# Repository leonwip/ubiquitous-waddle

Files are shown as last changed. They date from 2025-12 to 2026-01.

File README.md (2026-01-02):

# ubiquitous-waddle

This is an open-source dual channel CAN FD to USB-C adapter. It is meant to be
used with the Zephyr-based [CANnectivity][1] firmware.

## Firmware

### Building

Assuming you already have a working Zephyr development environment (see
[Getting Started Guide][2]), the firmware workspace can be initialized using:
```sh
west init -m "https://github.com/leonwip/ubiquitous-waddle" --mr main my-workspace
cd my-workspace
west update
```

Then to build the release variant (with reduced logging):
```sh
west build -b ubiquitous_waddle --sysbuild cannectivity/app -- -DSB_CONF_FILE=sysbuild-dfu.conf -DFILE_SUFFIX=usbd_next_release
```

### Flashing

To flash via JLink (SWD):
```sh
west flash --runner jlink
```

To flash via USB DFU:
```
dfu-util -a 0 -D build/app/zephyr/zephyr.signed.bin.dfu
```

## Example Usage

Verify successful connection:
```sh
$ lsusb | grep CANnectivity
Bus 005 Device 014: ID 1209:ca01 Generic CANnectivity USB to CAN adapter
```

Determine interface names:
```sh
$ ip link show type can
16: can0: <NOARP,ECHO> mtu 16 qdisc noop state DOWN mode DEFAULT group default qlen 10
    link/can
17: can1: <NOARP,ECHO> mtu 16 qdisc noop state DOWN mode DEFAULT group default qlen 10
    link/can
```

Bring up the interface (with FD on):
```sh
sudo ip link set can0 up type can bitrate 250000 dbitrate 1000000 fd on
```

Send some frames (`##1` opposed to just `#` turns on BRS):
```sh
cansend can0 123#11.22.33
cansend can0 123##111.22.33
```

## License

CANnectivity is licensed under the [Apache-2.0][3] license. This board is
licensed under the [CERN-OHL-P-2.0](./LICENSE) license.

[1]: https://github.com/CANnectivity/cannectivity
[2]: https://docs.zephyrproject.org/latest/develop/getting_started/index.html
[3]: https://github.com/CANnectivity/cannectivity/blob/main/LICENSE

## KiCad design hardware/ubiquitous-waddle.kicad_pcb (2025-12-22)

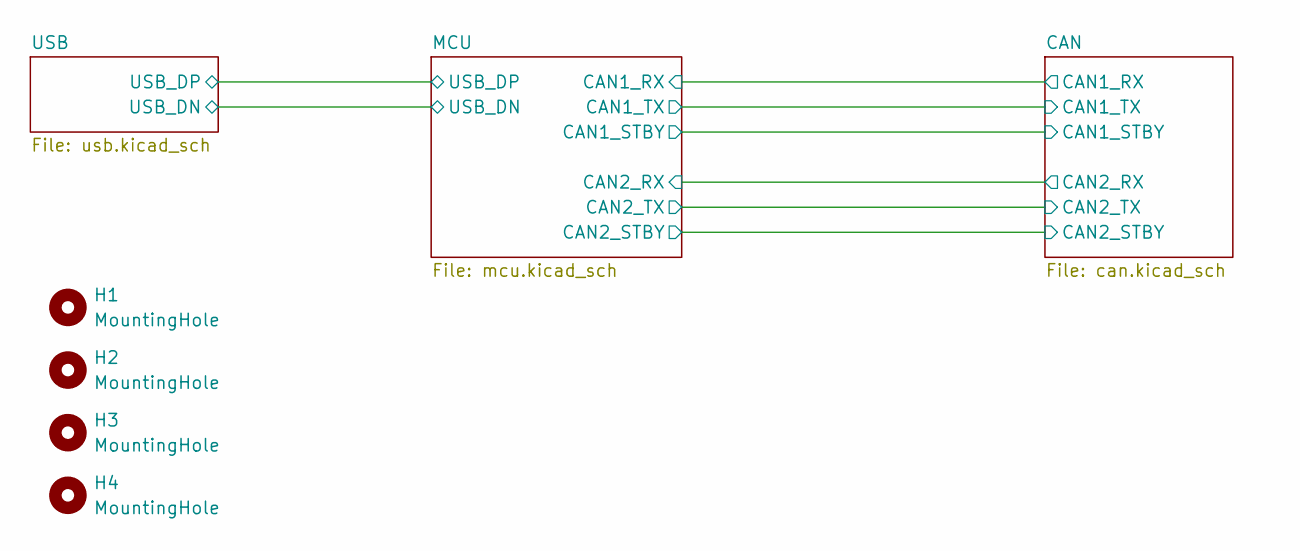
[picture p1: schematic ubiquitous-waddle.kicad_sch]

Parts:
H1, H2, H3, H4: MountingHole; MountingHole_2.7mm_M2.5

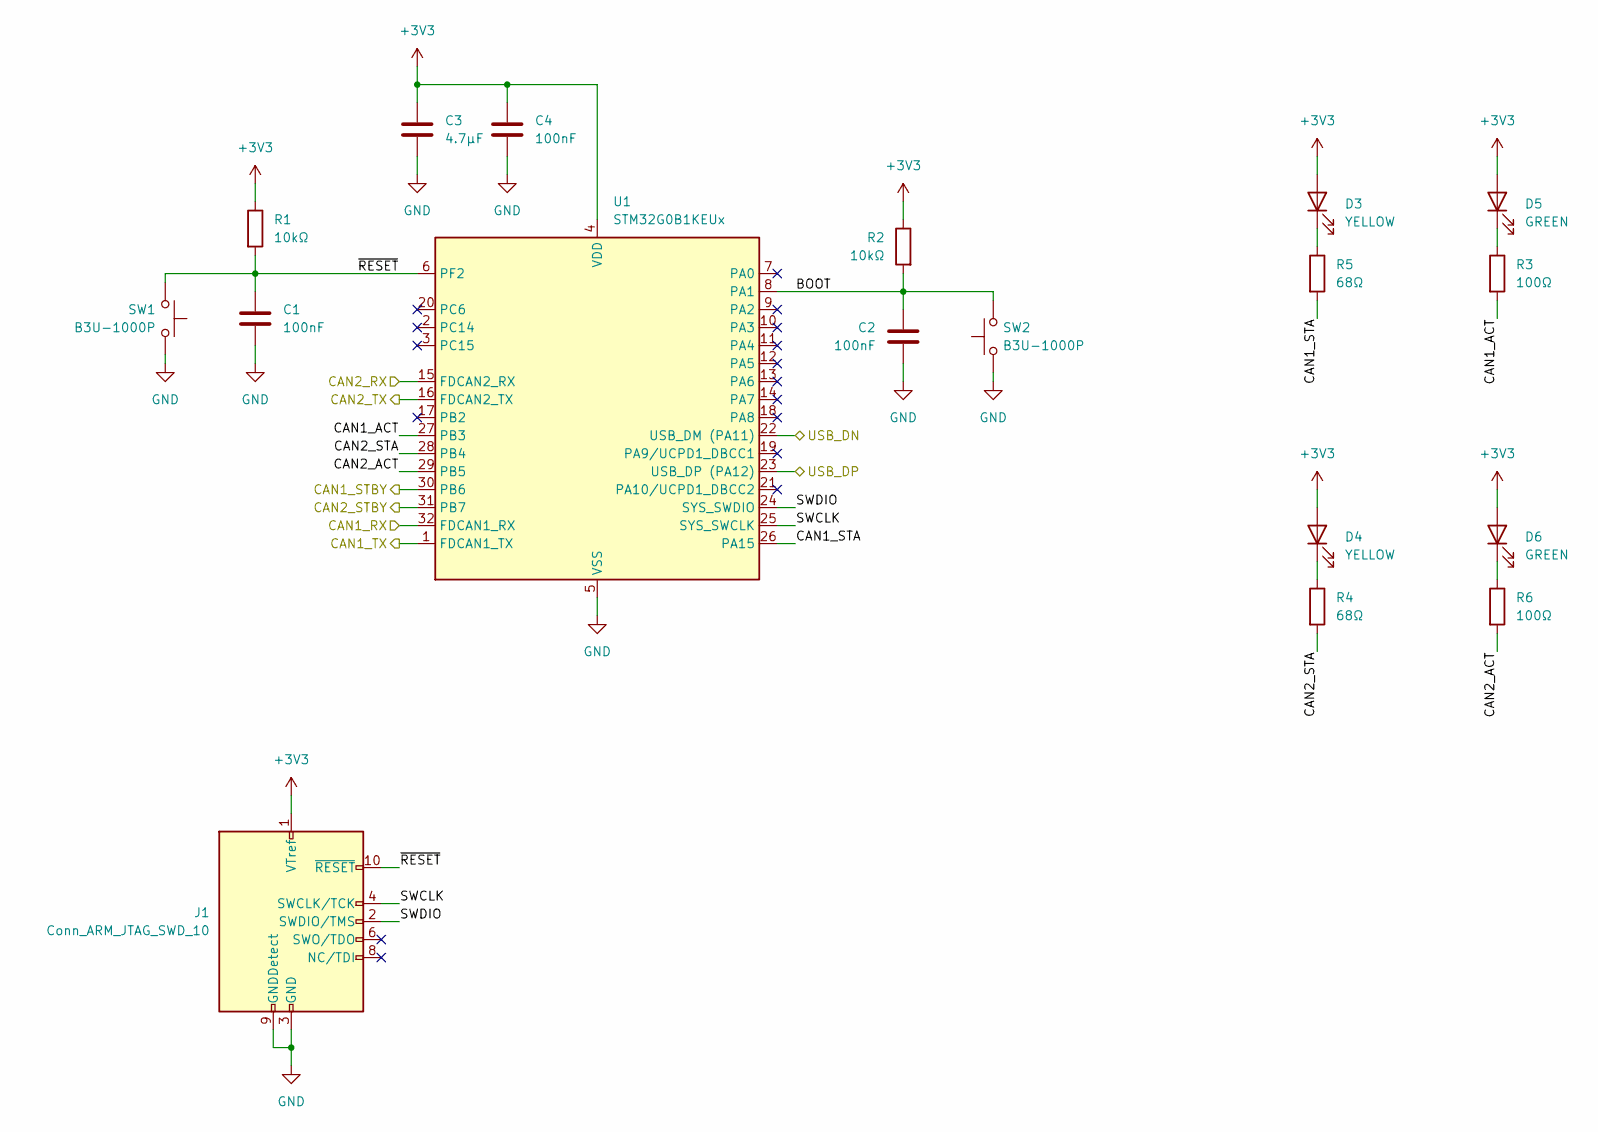
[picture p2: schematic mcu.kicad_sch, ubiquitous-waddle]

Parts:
C1, C2, C4: 100nF; C_0402_1005Metric; Mouser No 81-GRM155R71A104KA1D
C3: 4.7µF; C_0402_1005Metric; Mouser No 81-GRM155R61A475MEAD
D3, D4: YELLOW; LED_0603_1608Metric; Mouser No 710-150060YS55040
D5, D6: GREEN; LED_0603_1608Metric; Mouser No 710-150060GS55040
J1: Conn_ARM_JTAG_SWD_10; PinHeader_2x05_P1.27mm_Vertical_SMD; Mouser No 200-FTSH10501FDVK
R1, R2: 10kΩ; R_0402_1005Metric; Mouser No 603-RC0402FR-0710KL
R3, R6: 100Ω; R_0402_1005Metric; Mouser No 603-RC0402FR-07100RL
R4, R5: 68Ω; R_0402_1005Metric; Mouser No 603-RC0402FR-0768RL
SW1, SW2: B3U-1000P; SW_SPST_B3U-1000P; Mouser No 653-B3U-1000P
U1: STM32G0B1KEUx; QFN-32-1EP_5x5mm_P0.5mm_EP3.45x3.45mm_ThermalVias; Mouser No 511-STM32G0B1KEU6

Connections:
+3V3: C3.1, C4.1, D3.2 (A), D4.2 (A), D5.2 (A), D6.2 (A), J1.1 (VTref), R1.1, R2.1, U1.4 (VDD); also elsewhere on the board
/CAN/CAN1_RX: U1.32 (FDCAN1_RX); also elsewhere on the board
/CAN/CAN1_STBY: U1.30 (PB6); also elsewhere on the board
/CAN/CAN1_TX: U1.1 (FDCAN1_TX); also elsewhere on the board
/CAN/CAN2_RX: U1.15 (FDCAN2_RX); also elsewhere on the board
/CAN/CAN2_STBY: U1.31 (PB7); also elsewhere on the board
/CAN/CAN2_TX: U1.16 (FDCAN2_TX); also elsewhere on the board
/MCU/BOOT: C2.1, R2.2, SW2.2, U1.8 (PA1)
/MCU/CAN1_ACT: R3.2, U1.27 (PB3)
/MCU/CAN1_STA: R5.2, U1.26 (PA15)
/MCU/CAN2_ACT: R6.2, U1.29 (PB5)
/MCU/CAN2_STA: R4.2, U1.28 (PB4)
/MCU/SWCLK: J1.4 (SWCLK/TCK), U1.25 (SYS_SWCLK)
/MCU/SWDIO: J1.2 (SWDIO/TMS), U1.24 (SYS_SWDIO)
/MCU/USB_DN: U1.22 (USB_DM (PA11)); also elsewhere on the board
/MCU/USB_DP: U1.23 (USB_DP (PA12)); also elsewhere on the board
/MCU/~RESET: C1.1, J1.10 (~RESET), R1.2, SW1.2, U1.6 (PF2)
GND: C1.2, C2.2, C3.2, C4.2, J1.3 (GND), J1.5 (GND), J1.9 (GNDDetect), SW1.1, SW2.1, U1.5 (VSS), U1.33 (VSS); also elsewhere on the board
unnamed: D3.1 (K), R5.1
unnamed: D4.1 (K), R4.1
unnamed: D5.1 (K), R3.1
unnamed: D6.1 (K), R6.1

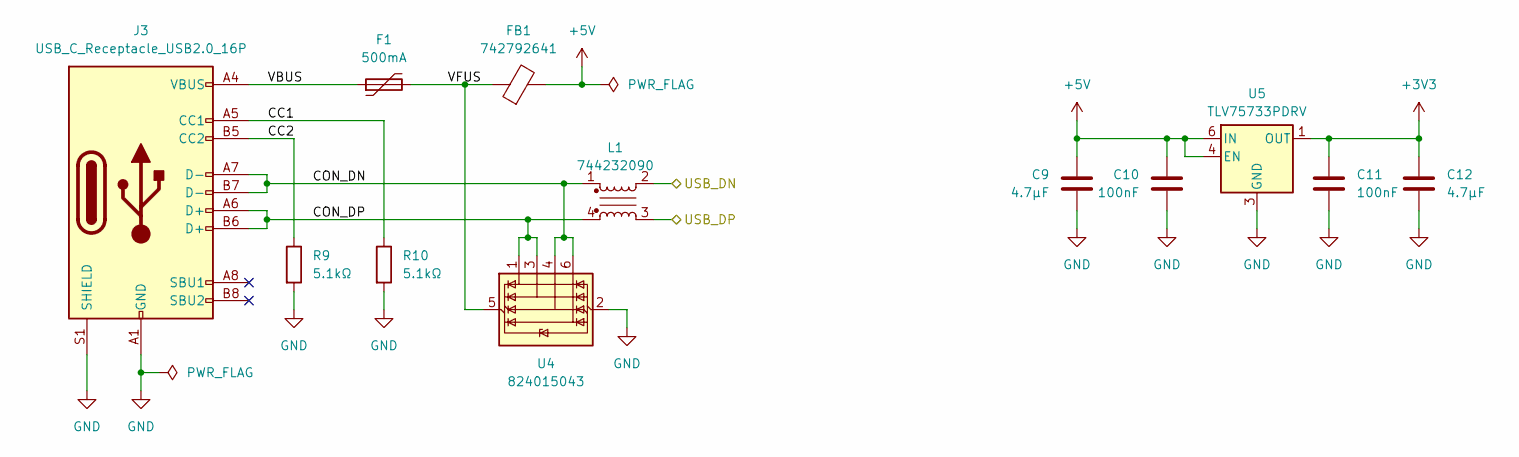
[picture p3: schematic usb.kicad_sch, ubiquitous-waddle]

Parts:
C9, C12: 4.7µF; C_0402_1005Metric; Mouser No 81-GRM155R61A475MEAD
C10, C11: 100nF; C_0402_1005Metric; Mouser No 81-GRM155R71A104KA1D
F1: 500mA; Fuse_0603_1608Metric; Mouser No 652-MF-FSML050/8-2
FB1: 742792641; L_0603_1608Metric; Mouser No 710-742792641
J3: USB_C_Receptacle_USB2.0_16P; USB_C_Receptacle_GCT_USB4105-xx-A_16P_TopMnt_Horizontal; Mouser No 640-USB4105-GF-A-060
L1: 744232090; L_CommonMode_Wurth_WE-CNSW-1206; Mouser No 710-744232090
R9, R10: 5.1kΩ; R_0402_1005Metric; Mouser No 71-CRCW0402-5.1K-E3
U4: 824015043; SOT-23-6; Mouser No 710-824015043
U5: TLV75733PDRV; WSON-6-1EP_2x2mm_P0.65mm_EP1x1.6mm; Mouser No 595-TLV75733PDRVR

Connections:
+3V3: C11.1, C12.1, U5.1 (OUT); also elsewhere on the board
+5V: C9.1, C10.1, FB1.2, U5.4 (EN), U5.6 (IN); also elsewhere on the board
/MCU/USB_DN: L1.2; also elsewhere on the board
/MCU/USB_DP: L1.3; also elsewhere on the board
/USB/CC1: J3.A5 (CC1), R10.1
/USB/CC2: J3.B5 (CC2), R9.1
/USB/CON_DN: J3.A7 (D-), J3.B7 (D-), L1.1, U4.4 (I/O3), U4.6 (I/O4)
/USB/CON_DP: J3.A6 (D+), J3.B6 (D+), L1.4, U4.1 (I/O1), U4.3 (I/O2)
/USB/VBUS: F1.1, J3.A4 (VBUS), J3.A9 (VBUS), J3.B4 (VBUS), J3.B9 (VBUS)
/USB/VFUS: F1.2, FB1.1, U4.5 (VBUS)
GND: C9.2, C10.2, C11.2, C12.2, J3.A1 (GND), J3.A12 (GND), J3.B1 (GND), J3.B12 (GND), J3.S1 (SHIELD), R9.2, R10.2, U4.2 (GND), U5.3 (GND), U5.7 (GND); also elsewhere on the board

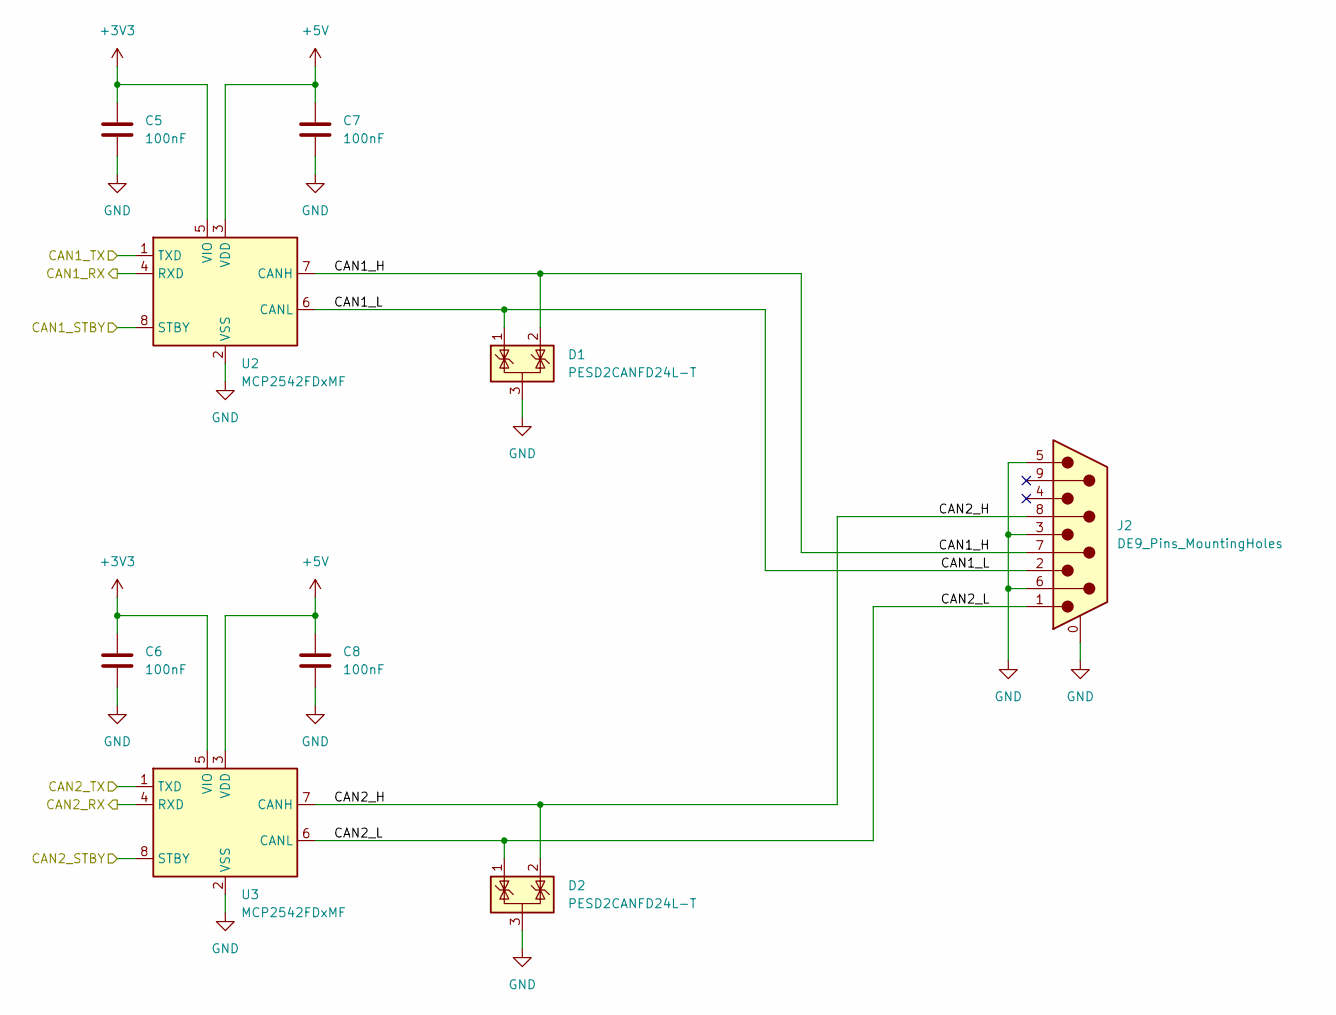
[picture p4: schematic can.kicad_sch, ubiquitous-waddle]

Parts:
C5, C6, C7, C8: 100nF; C_0402_1005Metric; Mouser No 81-GRM155R71A104KA1D
D1, D2: PESD2CANFD24L-T; SOT-23; Mouser No 771-PESD2CANFD24L-TR
J2: DE9_Pins_MountingHoles; DSUB-9_Pins_Horizontal_P2.77x2.84mm_EdgePinOffset9.90mm_Hou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; Mouser No 649-D09P13A4GV00LF
U2, U3: MCP2542FDxMF; DFN-8-1EP_3x3mm_P0.65mm_EP1.55x2.4mm; Mouser No 579-MCP2542FDT-E/MF

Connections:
+3V3: C5.1, C6.1, U2.5 (VIO), U3.5 (VIO); also elsewhere on the board
+5V: C7.1, C8.1, U2.3 (VDD), U3.3 (VDD); also elsewhere on the board
/CAN/CAN1_H: D1.2 (K), J2.7, U2.7 (CANH)
/CAN/CAN1_L: D1.1 (K), J2.2, U2.6 (CANL)
/CAN/CAN1_RX: U2.4 (RXD); also elsewhere on the board
/CAN/CAN1_STBY: U2.8 (STBY); also elsewhere on the board
/CAN/CAN1_TX: U2.1 (TXD); also elsewhere on the board
/CAN/CAN2_H: D2.2 (K), J2.8, U3.7 (CANH)
/CAN/CAN2_L: D2.1 (K), J2.1, U3.6 (CANL)
/CAN/CAN2_RX: U3.4 (RXD); also elsewhere on the board
/CAN/CAN2_STBY: U3.8 (STBY); also elsewhere on the board
/CAN/CAN2_TX: U3.1 (TXD); also elsewhere on the board
GND: C5.2, C6.2, C7.2, C8.2, D1.3 (A), D2.3 (A), J2.0 (PAD), J2.3, J2.5, J2.6, U2.2 (VSS), U2.9 (VSS), U3.2 (VSS), U3.9 (VSS); also elsewhere on the board

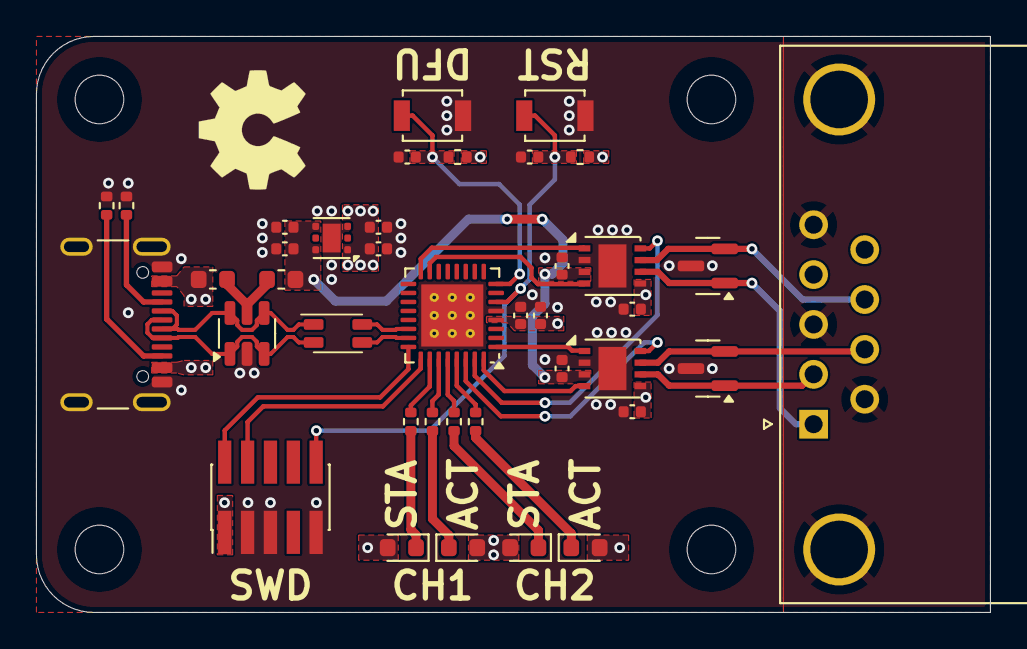
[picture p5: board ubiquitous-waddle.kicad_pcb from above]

Board: 4 copper layers, 53.0 x 32.0 mm, 43 parts (0 on the bottom side), 33 nets.

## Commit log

2025-10-12 fix: remove obsolete sheet
    [led.kicad_sch]
2025-12-22 add hardware revision v2
    [can.kicad_sch, mcu.kicad_sch, ubiquitous-waddle.kicad_pcb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]
2026-01-02 feat!: use `device_next`, bump dependencies
    Switch to the experimental `device_next` USB device stack.
    Bump Zephyr and CANnectivity to v4.3.0 and v1.3.0 respectively.
